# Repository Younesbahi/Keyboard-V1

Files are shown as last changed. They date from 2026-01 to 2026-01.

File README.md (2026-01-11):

# Mechanical Keyboard V1

## What this is
This is a custom mechanical keyboard that I designed from scratch. I designed the PCB, selected all the components, and created the case in Fusion 360.

The keyboard uses a Raspberry Pi Pico microcontroller, a diode matrix, and a custom layout. It also has a 0.96-inch OLED screen.

## Features
- Custom keyboard layout
- Number row acts as function keys when Fn is held
- Mechanical MX-style switches
- Diode matrix
-  OLED screen
- 3D-printed case

## Layout

## Bill of Materials (BOM)

| Item | Description | Quantity | Unit Price | Total Price | URL | Running Total ($ with Tax) | Total w/ Shipping |
|---|---|---|---|---|---|---|---|
| PCB | Keyboard PCB | 5 | $3.46 | $17.30 | [JLCPCB](https://jlcpcb.com/) | $30.31 | $33.65 |
| MCU | Raspberry Pi Pico | 1 | $2.64 | $2.64 | [AliExpress](https://www.aliexpress.com/item/1005006615944063.html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) | $2.64 | $2.64 |
| Switches | Outemu Cream Yellow | 70 | $0.267 | $18.69 | [AliExpress](https://www.aliexpress.com/item/1005006263528658.html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) | $18.69 | $18.69 |
| Diodes | 1N4148 DO-35 IN4148 | 100 | $0.0202 | $2.02 | [AliExpress](https://www.aliexpress.com/item/1005007807649334.html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) | $2.02 | $2.02 |
| Stabilizers | PCB-mount stabilizers | 1 | $6.86 | $6.86 | [AliExpress](https://www.aliexpress.com/item/1005004229140548.html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) | $6.86 | $6.86 |
| Standoff | M3 Standoffs 6mm | 50 | $0.0386 | $1.93 | [AliExpress](https://www.aliexpress.com/item/32539100523.html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) | $1.93 | $1.93 |
| Screws | M3 Screws 5mm | 50 | $0.0322 | $1.61 | [AliExpress](https://www.aliexpress.com/item/32539100523.html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) | $1.61 | $1.61 |
| Inserts | M3 Heat inserts | 50 | $0.0452 | $2.26 | [AliExpress](https://www.aliexpress.com/item/1005003582355741.html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) | $2.26 | $2.26 |
| KeyCaps | Keycaps for Cherry MX Switches | 1 | $11.49 | $11.49 | [AliExpress](https://www.aliexpress.com/item/1005009580866548.html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) | $11.49 | $11.49 |
| Case | 3D Printed case | 1 | - | - | - | - | - |
| I2C OLED 0.91" | OLED screen | 1 | $2.53 | $2.53 | [AliExpress](https://www.aliexpress.com/item/1005006297182727.html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) | $2.53 | $2.53 |

**Total Cost:** $83.68  (Not including Case)
| Schematic | PCB Layout | PCB render |
|---|---|---|
| |  ||

## Render 
top view

side view

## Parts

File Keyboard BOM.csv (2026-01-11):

Item | Description | Quantity | Unit price | Total price | URL | Running Total ($ with Tax) | Total w/ Shipping
PCB | Keyboard PCB | 5 | $3.46 | $17.30 | https://jlcpcb.com/ | $30.31 | $33.65
MCU | Raspberry Pi Pico | 1 | $2.64 | $2.64 | https://www.aliexpress.com/item/1005006615944063.html?mp=1 | $2.64 | $2.64
Switches | Otemu Cream yellow | 70 | $0.27 | $18.69 | https://www.aliexpress.com/item/1005006263528658.html?mp=1 | $18.69 | $18.69
Diodes | 1N4148 DO-35 IN4148 | 100 | $0.02 | $2.02 | https://www.aliexpress.com/item/1005007807649334.html?mp=1 | $2.02 | $2.02
Stabilizers | PCB-mount stabilizers | 1 | $6.86 | $6.86 | https://www.aliexpress.com/item/1005004229140548.html?mp=1 | $6.86 | $6.86
Standoff | M3 Standoffs 6mm | 50 | $0.04 | $1.93 | https://www.aliexpress.com/item/32539100523.html?mp=1 | $1.93 | $1.93
Screws | M3 Screws 5mm | 50 | $0.03 | $1.61 | https://www.aliexpress.com/item/32539100523.html?mp=1 | $1.61 | $1.61
Inserts | M3 Heat inserts | 50 | $0.05 | $2.26 | https://www.aliexpress.com/item/1005003582355741.html?mp=1 | $2.26 | $2.26
KeyCaps | Keycaps for Cherry MX Switches | 1 | $11.49 | $11.49 | https://www.aliexpress.com/item/1005009580866548.html?mp=1 | $11.49 | $11.49
case | 3D Printed case | 1 | - | - | - | - | -
L2C OLED 0.91 inch | OLED screen | 1 | $2.53 | $2.53 | https://www.aliexpress.com/item/1005006297182727.html?mp=1 | $2.53 | $2.53
 |  |  |  |  |  |  | $83.68

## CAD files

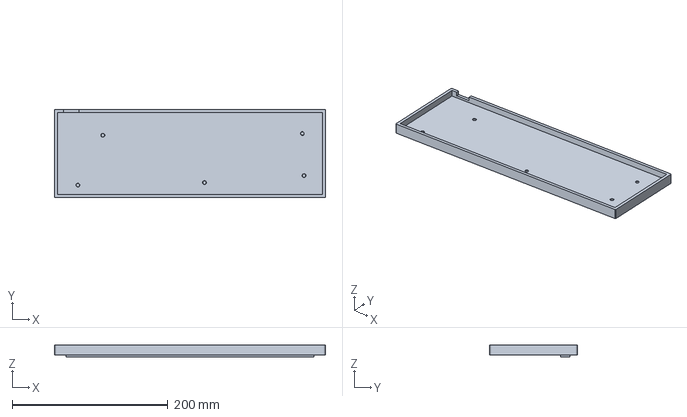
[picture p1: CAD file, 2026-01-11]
Case/Keyboard Case.step
348.0 x 113.0 x 16.0 mm

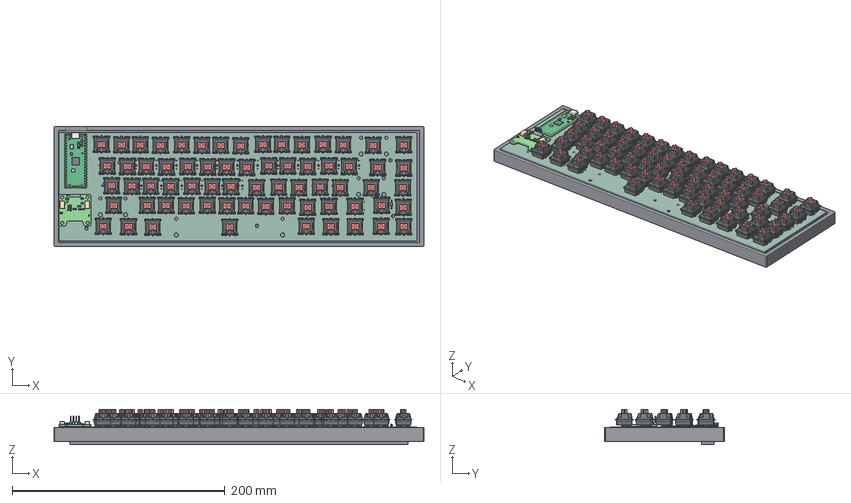
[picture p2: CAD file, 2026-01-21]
Keyboard with components.step
348.0 x 113.0 x 32.9 mm

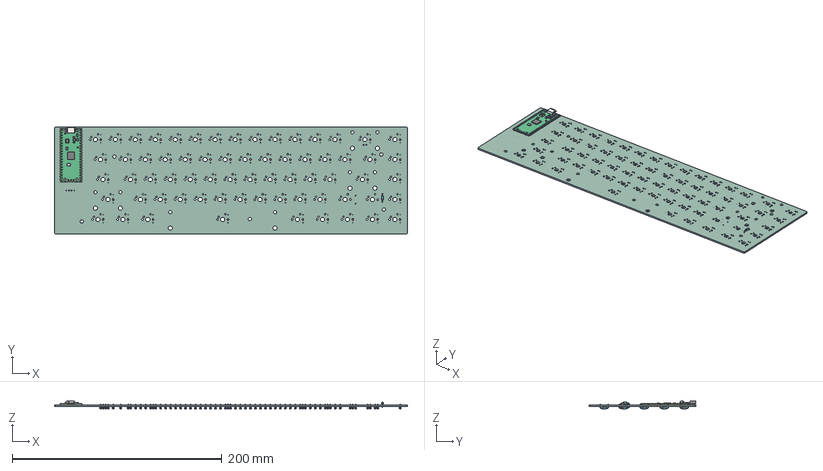
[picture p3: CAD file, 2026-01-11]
PCB/Keyboard.step
336.8 x 102.0 x 7.94 mm
RaspberryPi_Pico
D_DO-35_SOD27_P7.62mm_Horizontal x 67
Keyboard_PCB

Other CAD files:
Case/Keyboard Case.f3d

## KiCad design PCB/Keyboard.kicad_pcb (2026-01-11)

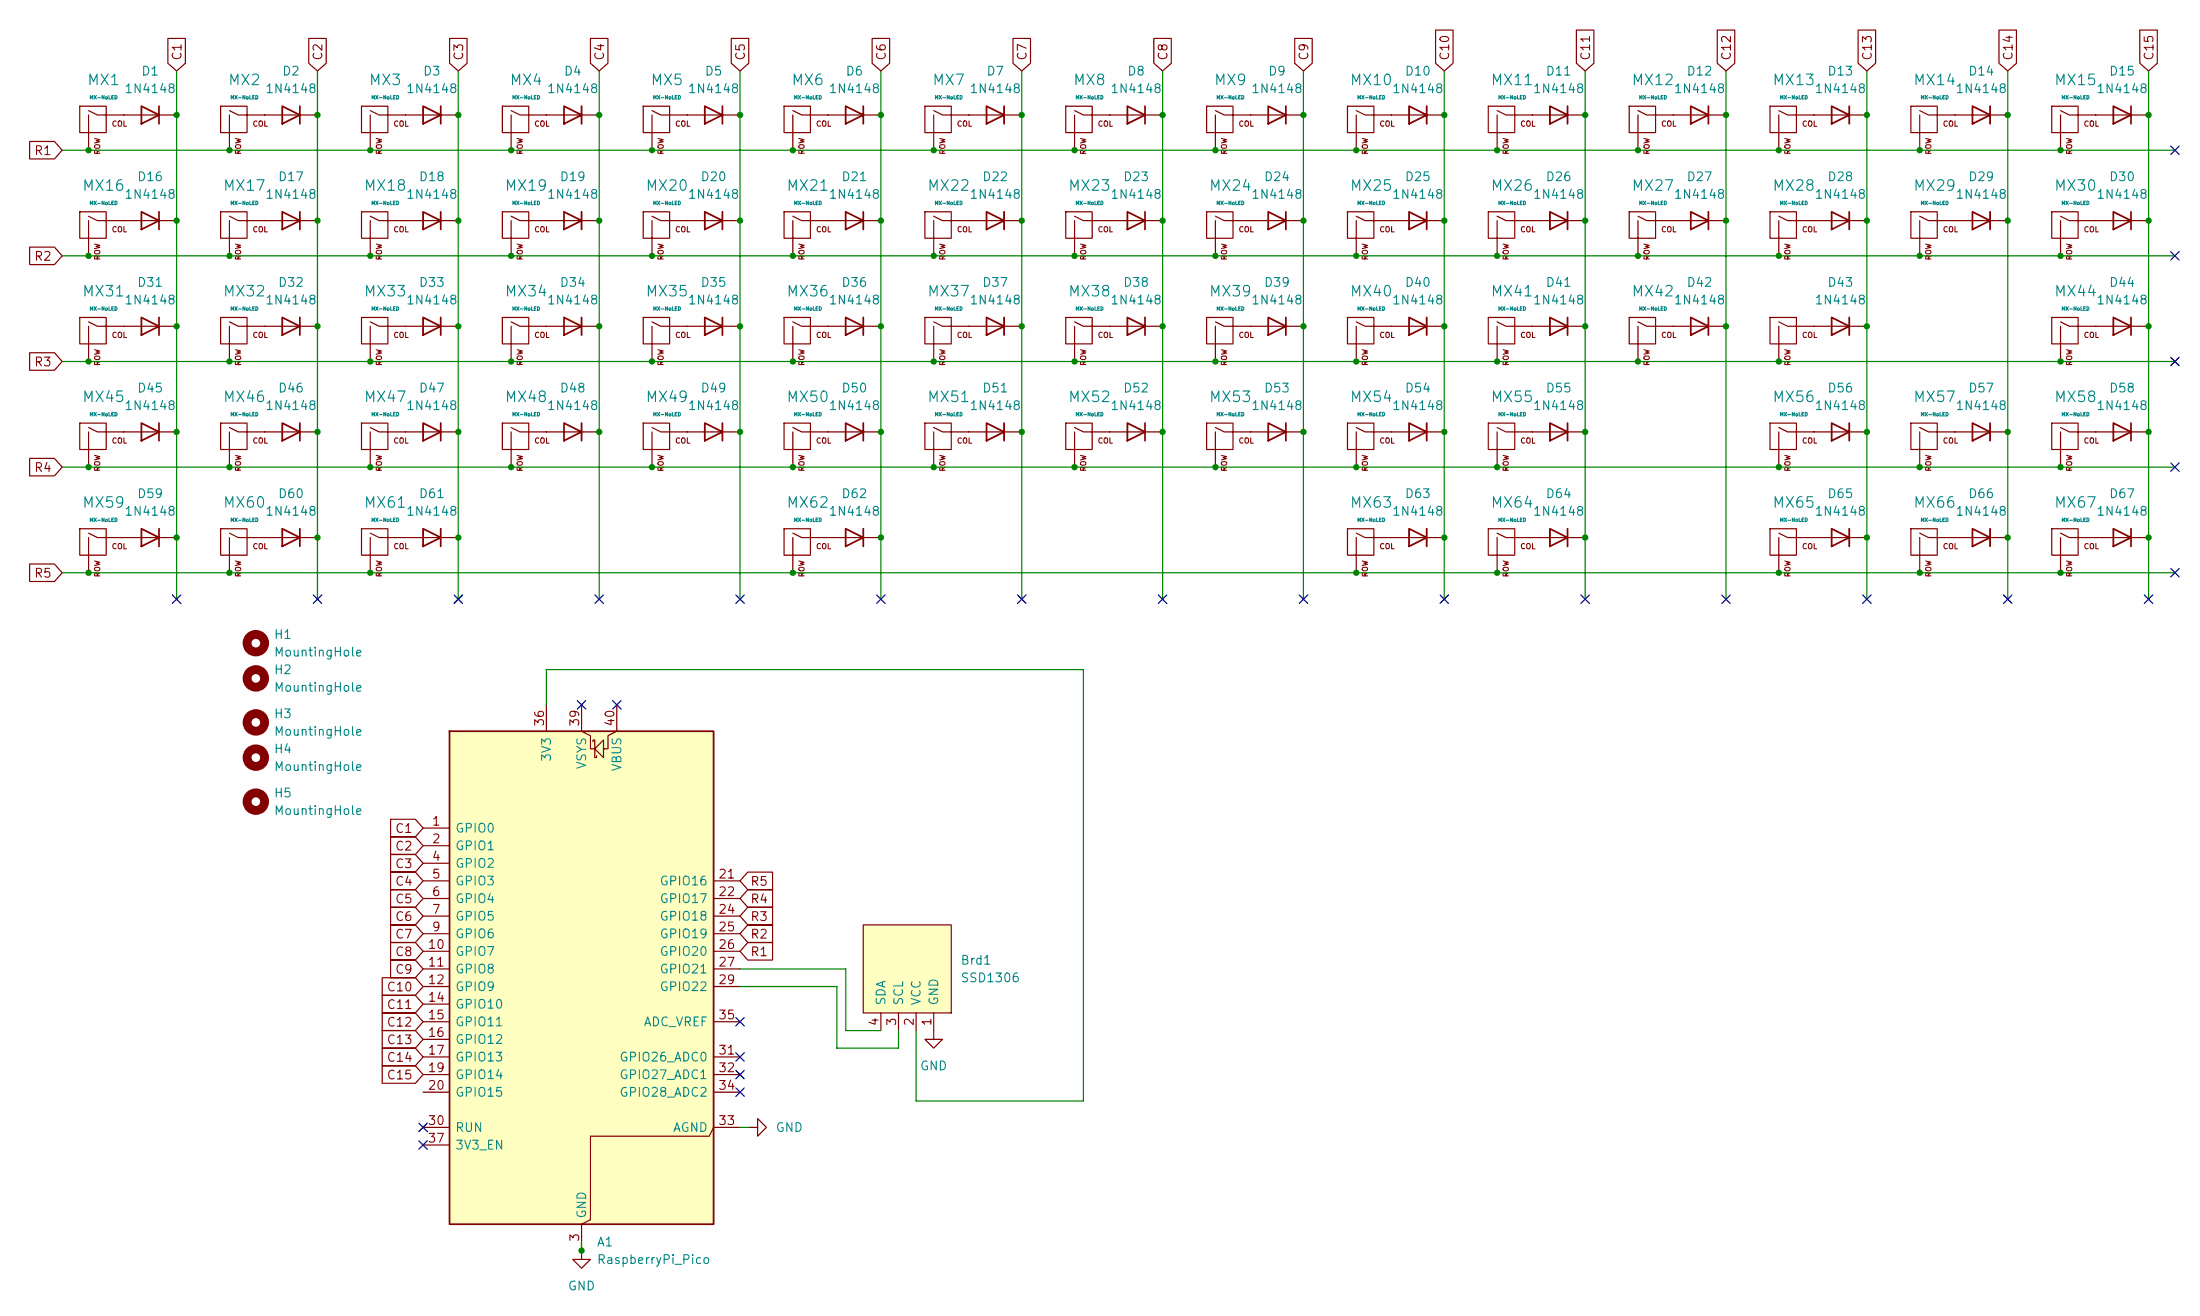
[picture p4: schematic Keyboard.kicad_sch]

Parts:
A1: RaspberryPi_Pico; RaspberryPi_Pico_Common
Brd1: SSD1306; 128x64OLED
D1, D2, D3, D4, D5, D6, D7, D8, D9, D10, D11, D12, D13, D14, D15, D16, D17, D18, D19, D20, D21, D22, D23, D24, D25, D26, D27, D28, D29, D30, D31, D32, D33, D34, D35, D36, D37, D38, D39, D40, D41, D42, D43, D44, D45, D46, D47, D48, D49, D50, D51, D52, D53, D54, D55, D56, D57, D58, D59, D60, D61, D62, D63, D64, D65, D66, D67: 1N4148; D_DO-35_SOD27_P7.62mm_Horizontal
H1, H2, H3, H4, H5: MountingHole; MountingHole_3.2mm_M3
MX1, MX2, MX3, MX4, MX5, MX6, MX7, MX8, MX9, MX10, MX11, MX12, MX13, MX15, MX17, MX18, MX19, MX20, MX21, MX22, MX23, MX24, MX25, MX26, MX27, MX28, MX30, MX32, MX33, MX34, MX35, MX36, MX37, MX38, MX39, MX40, MX41, MX42, MX44, MX46, MX47, MX48, MX49, MX50, MX51, MX52, MX53, MX54, MX55, MX58, MX67: MX-NoLED; MXOnly-1U-NoLED
MX14: MX-NoLED; MXOnly-2U
MX16, MX29, MX56: MX-NoLED; MXOnly-1.5U-NoLED
MX31: MX-NoLED; MXOnly-1.75U-NoLED
MX43, MX45: MX-NoLED; MXOnly-2.25U-NoLED
MX57, MX59, MX60, MX61, MX63, MX64, MX65, MX66: MX-NoLED; MXOnly-1.25U-NoLED
MX62: MX-NoLED; MXOnly-6.25U-NoLED

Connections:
C1: A1.1 (GPIO0), D1.1 (K), D16.1 (K), D31.1 (K), D45.1 (K), D59.1 (K)
C2: A1.2 (GPIO1), D2.1 (K), D17.1 (K), D32.1 (K), D46.1 (K), D60.1 (K)
C3: A1.4 (GPIO2), D3.1 (K), D18.1 (K), D33.1 (K), D47.1 (K), D61.1 (K)
C4: A1.5 (GPIO3), D4.1 (K), D19.1 (K), D34.1 (K), D48.1 (K)
C5: A1.6 (GPIO4), D5.1 (K), D20.1 (K), D35.1 (K), D49.1 (K)
C6: A1.7 (GPIO5), D6.1 (K), D21.1 (K), D36.1 (K), D50.1 (K), D62.1 (K)
C7: A1.9 (GPIO6), D7.1 (K), D22.1 (K), D37.1 (K), D51.1 (K)
C8: A1.10 (GPIO7), D8.1 (K), D23.1 (K), D38.1 (K), D52.1 (K)
C9: A1.11 (GPIO8), D9.1 (K), D24.1 (K), D39.1 (K), D53.1 (K)
C10: A1.12 (GPIO9), D10.1 (K), D25.1 (K), D40.1 (K), D54.1 (K), D63.1 (K)
C11: A1.14 (GPIO10), D11.1 (K), D26.1 (K), D41.1 (K), D55.1 (K), D64.1 (K)
C12: A1.15 (GPIO11), D12.1 (K), D27.1 (K), D42.1 (K)
C13: A1.16 (GPIO12), D13.1 (K), D28.1 (K), D43.1 (K), D56.1 (K), D65.1 (K)
C14: A1.17 (GPIO13), D14.1 (K), D29.1 (K), D57.1 (K), D66.1 (K)
C15: A1.19 (GPIO14), D15.1 (K), D30.1 (K), D44.1 (K), D58.1 (K), D67.1 (K)
GND: A1.3 (GND), A1.8 (GND), A1.13 (GND), A1.18 (GND), A1.23 (GND), A1.28 (GND), A1.33 (AGND), A1.38 (GND), Brd1.1 (GND)
unnamed: A1.36 (3V3), Brd1.2 (VCC)
unnamed: A1.27 (GPIO21), Brd1.4 (SDA)
unnamed: A1.29 (GPIO22), Brd1.3 (SCL)
unnamed: D1.2 (A), MX1.1 (COL)
unnamed: D2.2 (A), MX2.1 (COL)
unnamed: D3.2 (A), MX3.1 (COL)
unnamed: D4.2 (A), MX4.1 (COL)
unnamed: D5.2 (A), MX5.1 (COL)
unnamed: D6.2 (A), MX6.1 (COL)
unnamed: D7.2 (A), MX7.1 (COL)
unnamed: D8.2 (A), MX8.1 (COL)
unnamed: D9.2 (A), MX9.1 (COL)
unnamed: D10.2 (A), MX10.1 (COL)
unnamed: D11.2 (A), MX11.1 (COL)
unnamed: D12.2 (A), MX12.1 (COL)
unnamed: D13.2 (A), MX13.1 (COL)
unnamed: D14.2 (A), MX14.1 (COL)
unnamed: D15.2 (A), MX15.1 (COL)
unnamed: D16.2 (A), MX16.1 (COL)
unnamed: D17.2 (A), MX17.1 (COL)
unnamed: D18.2 (A), MX18.1 (COL)
unnamed: D19.2 (A), MX19.1 (COL)
unnamed: D20.2 (A), MX20.1 (COL)
unnamed: D21.2 (A), MX21.1 (COL)
unnamed: D22.2 (A), MX22.1 (COL)
unnamed: D23.2 (A), MX23.1 (COL)
unnamed: D24.2 (A), MX24.1 (COL)
unnamed: D25.2 (A), MX25.1 (COL)
unnamed: D26.2 (A), MX26.1 (COL)
unnamed: D27.2 (A), MX27.1 (COL)
unnamed: D28.2 (A), MX28.1 (COL)
unnamed: D29.2 (A), MX29.1 (COL)
unnamed: D30.2 (A), MX30.1 (COL)
unnamed: D31.2 (A), MX31.1 (COL)
unnamed: D32.2 (A), MX32.1 (COL)
unnamed: D33.2 (A), MX33.1 (COL)
unnamed: D34.2 (A), MX34.1 (COL)
unnamed: D35.2 (A), MX35.1 (COL)
unnamed: D36.2 (A), MX36.1 (COL)
unnamed: D37.2 (A), MX37.1 (COL)
unnamed: D38.2 (A), MX38.1 (COL)
unnamed: D39.2 (A), MX39.1 (COL)
unnamed: D40.2 (A), MX40.1 (COL)
unnamed: D41.2 (A), MX41.1 (COL)
unnamed: D42.2 (A), MX42.1 (COL)
unnamed: D43.2 (A), MX43.1 (COL)
unnamed: D44.2 (A), MX44.1 (COL)
unnamed: D45.2 (A), MX45.1 (COL)
unnamed: D46.2 (A), MX46.1 (COL)
unnamed: D47.2 (A), MX47.1 (COL)
unnamed: D48.2 (A), MX48.1 (COL)
unnamed: D49.2 (A), MX49.1 (COL)
unnamed: D50.2 (A), MX50.1 (COL)
unnamed: D51.2 (A), MX51.1 (COL)
unnamed: D52.2 (A), MX52.1 (COL)
unnamed: D53.2 (A), MX53.1 (COL)
unnamed: D54.2 (A), MX54.1 (COL)
unnamed: D55.2 (A), MX55.1 (COL)
unnamed: D56.2 (A), MX56.1 (COL)
unnamed: D57.2 (A), MX57.1 (COL)
unnamed: D58.2 (A), MX58.1 (COL)
unnamed: D59.2 (A), MX59.1 (COL)
unnamed: D60.2 (A), MX60.1 (COL)
unnamed: D61.2 (A), MX61.1 (COL)
unnamed: D62.2 (A), MX62.1 (COL)
unnamed: D63.2 (A), MX63.1 (COL)
unnamed: D64.2 (A), MX64.1 (COL)
unnamed: D65.2 (A), MX65.1 (COL)
unnamed: D66.2 (A), MX66.1 (COL)
unnamed: D67.2 (A), MX67.1 (COL)
R1: A1.26 (GPIO20), MX1.2 (ROW), MX2.2 (ROW), MX3.2 (ROW), MX4.2 (ROW), MX5.2 (ROW), MX6.2 (ROW), MX7.2 (ROW), MX8.2 (ROW), MX9.2 (ROW), MX10.2 (ROW), MX11.2 (ROW), MX12.2 (ROW), MX13.2 (ROW), MX14.2 (ROW), MX15.2 (ROW)
R2: A1.25 (GPIO19), MX16.2 (ROW), MX17.2 (ROW), MX18.2 (ROW), MX19.2 (ROW), MX20.2 (ROW), MX21.2 (ROW), MX22.2 (ROW), MX23.2 (ROW), MX24.2 (ROW), MX25.2 (ROW), MX26.2 (ROW), MX27.2 (ROW), MX28.2 (ROW), MX29.2 (ROW), MX30.2 (ROW)
R3: A1.24 (GPIO18), MX31.2 (ROW), MX32.2 (ROW), MX33.2 (ROW), MX34.2 (ROW), MX35.2 (ROW), MX36.2 (ROW), MX37.2 (ROW), MX38.2 (ROW), MX39.2 (ROW), MX40.2 (ROW), MX41.2 (ROW), MX42.2 (ROW), MX43.2 (ROW), MX44.2 (ROW)
R4: A1.22 (GPIO17), MX45.2 (ROW), MX46.2 (ROW), MX47.2 (ROW), MX48.2 (ROW), MX49.2 (ROW), MX50.2 (ROW), MX51.2 (ROW), MX52.2 (ROW), MX53.2 (ROW), MX54.2 (ROW), MX55.2 (ROW), MX56.2 (ROW), MX57.2 (ROW), MX58.2 (ROW)
R5: A1.21 (GPIO16), MX59.2 (ROW), MX60.2 (ROW), MX61.2 (ROW), MX62.2 (ROW), MX63.2 (ROW), MX64.2 (ROW), MX65.2 (ROW), MX66.2 (ROW), MX67.2 (ROW)

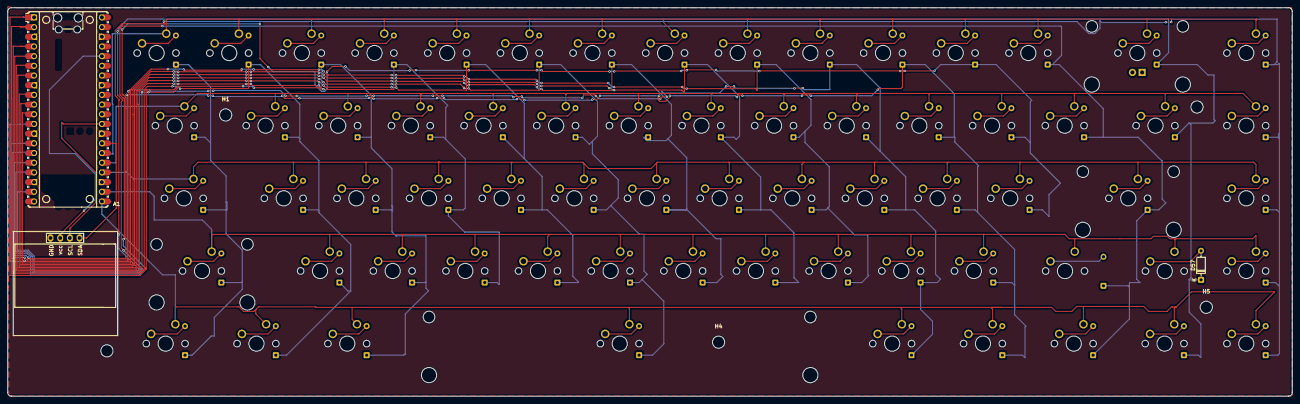
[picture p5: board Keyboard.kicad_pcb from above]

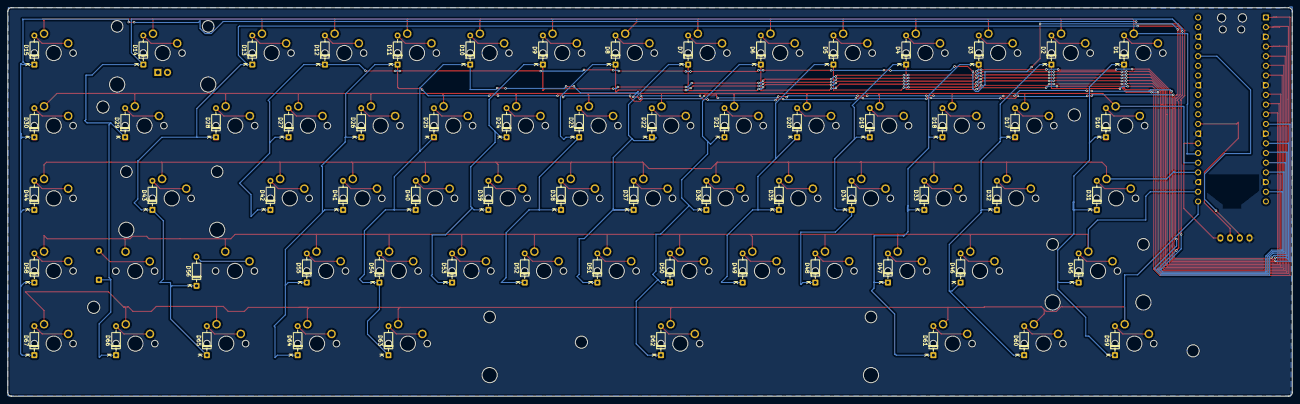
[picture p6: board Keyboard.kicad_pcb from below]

Board: 2 copper layers, 336.8 x 101.9 mm, 141 parts (66 on the bottom side), 91 nets.
